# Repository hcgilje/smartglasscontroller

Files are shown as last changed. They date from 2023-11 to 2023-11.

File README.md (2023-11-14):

# smartglasscontroller
A shield for Arduino Mega to control 5 smartglass break out boards
This shield was made to work together with the smart glass controller breakout boads: https://github.com/OBauck/smart-glass-controller-breakout

It consists of 5 CAT connectors, one DMX output and a RTC module.

Created for my KORO commission for Drammen Tinghus 2023.

The files are made with KiCad 7.0
The boards where fabricated at JLCPBC using the files in the Production folder

DT-doku-MEGAshield

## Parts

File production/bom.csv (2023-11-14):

Designator | Footprint | Quantity | Value | LCSC Part #
J1 | PinSocket_1x08_P2.54mm_Vertical | 1 | Power
J10, J11, J12, J13, J8, J9 | RJ45_Amphenol_54602-x08_Horizontal | 6 | RJ45
J14 | TerminalBlock_bornier-3_P5.08mm | 1 | DMX
J15 | TerminalBlock_bornier-2_P5.08mm | 1 | 24v
J16 | TerminalBlock_bornier-2_P5.08mm | 1 | rs485
J17 | TerminalBlock_bornier-2_P5.08mm | 1 | +5v
J2 | PinSocket_1x10_P2.54mm_Vertical | 1 | PWM
J3, J5 | PinSocket_1x08_P2.54mm_Vertical | 2 | Analog
J4 | PinSocket_1x08_P2.54mm_Vertical | 1 | PWM
J6 | PinSocket_1x08_P2.54mm_Vertical | 1 | Communication
J7 | PinSocket_2x18_P2.54mm_Vertical | 1 | Digital
R1 | 0402 | 1 | 120R
R2 | 0402 | 1 | 100R
U1, U3 | SOIC-8-1EP_3.9x4.9mm_P1.27mm_EP2.41x3.81mm | 2 | MAX485E
U2 | TO-252-2 | 1 | LM78M05_TO252

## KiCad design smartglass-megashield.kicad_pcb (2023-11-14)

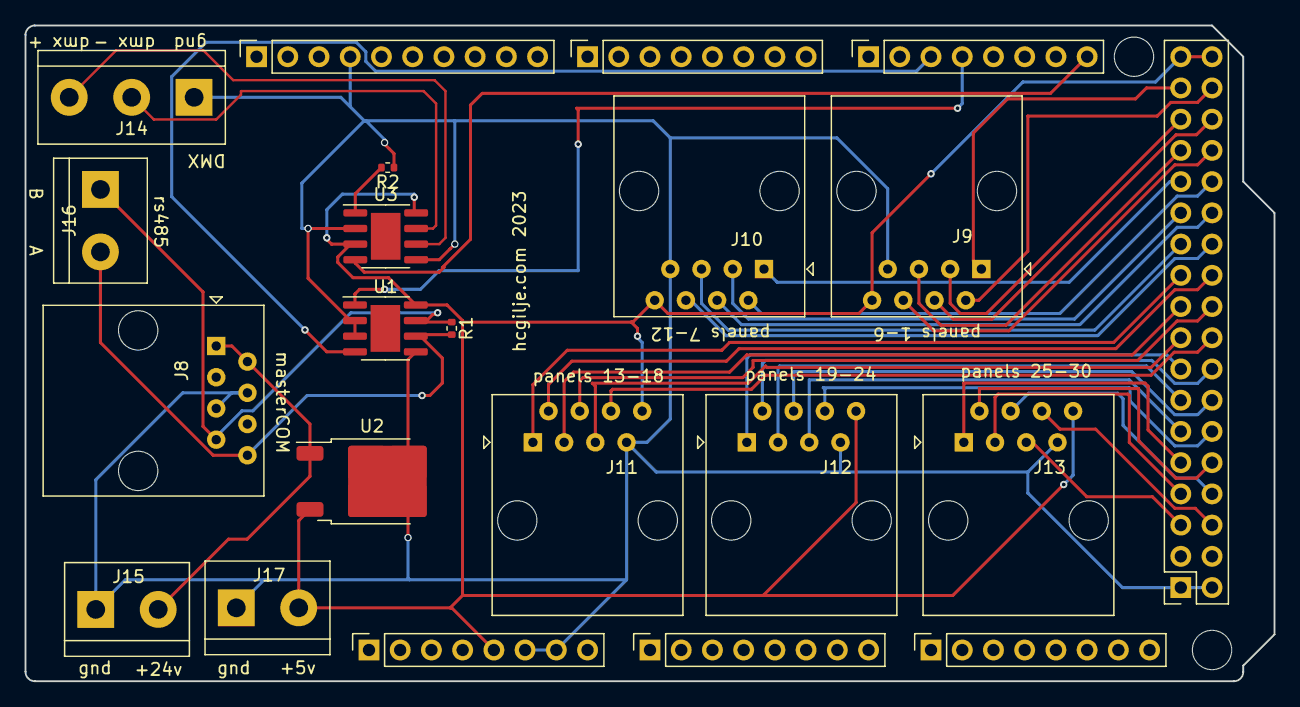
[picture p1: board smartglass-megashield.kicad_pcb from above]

Board: 2 copper layers, 101.6 x 53.3 mm, 24 parts (0 on the bottom side), 41 nets.

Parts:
J1: Power; PinSocket_1x08_P2.54mm_Vertical
J2: PWM; PinSocket_1x10_P2.54mm_Vertical
J3, J5: Analog; PinSocket_1x08_P2.54mm_Vertical
J4: PWM; PinSocket_1x08_P2.54mm_Vertical
J6: Communication; PinSocket_1x08_P2.54mm_Vertical
J7: Digital; PinSocket_2x18_P2.54mm_Vertical
J8, J9, J10, J11, J12, J13: RJ45; RJ45_Amphenol_54602-x08_Horizontal
J14: DMX; TerminalBlock_bornier-3_P5.08mm
J15: 24v; TerminalBlock_bornier-2_P5.08mm
J16: rs485; TerminalBlock_bornier-2_P5.08mm
J17: +5v; TerminalBlock_bornier-2_P5.08mm
MH5, MH6: MountingHole_3.2mm
R1: 120R; R_0402_1005Metric
R2: 100R; R_0402_1005Metric
U1, U3: MAX485E; SOIC-8-1EP_3.9x4.9mm_P1.27mm_EP2.41x3.81mm
U2: LM78M05_TO252; TO-252-2

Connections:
+5V: J1.5, J7.35, J7.36, J9.8, J10.8, J11.8, J12.8, J13.8, J17.2, U1.8 (VCC), U2.3 (VO), U3.3 (DE), U3.8 (VCC)
+24V: J8.1, J8.2, J15.2, U2.1 (VI)
A: J8.8, J16.2, R1.2, U1.6 (A)
B: J8.7, J16.1, R1.1, U1.7 (B)
DMX+: J14.3, U3.6 (A)
DMX-: J14.2, U3.7 (B)
GND: J1.6, J1.7, J2.4, J7.1, J7.2, J8.4, J8.5, J9.7, J10.7, J11.7, J12.7, J13.7, J14.1, J15.1, J17.1, R2.1, U1.2 (~RE), U1.3 (DE), U1.5 (GND), U2.2 (GND), U3.2 (~RE), U3.5 (GND)
unnamed: R2.2, U3.1 (RO)
O1: J7.33, J9.1
O2: J7.34, J9.2
O3: J7.31, J9.3
O4: J7.32, J9.4
O5: J7.29, J9.5
O6: J7.30, J9.6
O7: J7.27, J10.1
O8: J7.28, J10.2
O9: J7.25, J10.3
O10: J7.26, J10.4
O11: J7.23, J10.5
O12: J7.24, J10.6
O13: J7.21, J11.1
O14: J7.22, J11.2
O15: J7.19, J11.3
O16: J7.20, J11.4
O17: J7.17, J11.5
O18: J7.18, J11.6
O19: J7.15, J12.1
O20: J7.16, J12.2
O21: J7.13, J12.3
O22: J7.14, J12.4
O23: J7.11, J12.5
O24: J7.12, J12.6
O25: J7.9, J13.1
O26: J7.10, J13.2
O27: J7.7, J13.3
O28: J7.8, J13.4
O29: J7.5, J13.5
O30: J7.6, J13.6
dmx input: J6.8, U3.4 (DI)
sRX: J6.4, U1.1 (RO)
sTX: J6.3, U1.4 (DI)
